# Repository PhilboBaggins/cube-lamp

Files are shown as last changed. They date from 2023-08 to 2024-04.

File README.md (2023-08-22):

# Cube lamp stand

A lamp that shines light through a cube of resin. Various junk could be embedded in the resin to make it look interesting.

TODO: Add photo of completed lamp

## Licence

Copyright © 2023 Phil Baldwin

This work is licensed under a Creative Commons Attribution-ShareAlike 4.0 International License.

You should have received a copy of the license along with this work. If not, see <http://creativecommons.org/licenses/by-sa/4.0/>.

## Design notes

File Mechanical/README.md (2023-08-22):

# Cube lamp stand

A stand designed to hold the [PCB](../PCB/) and resin cube. The stand is intended to be 3D printed.

TODO: Add photo

## Design notes

There are several models of the stand. All were designed in [Blender](https://www.blender.org/) and saved as `Cube lamp stand.blend`. Each model was exported from Blender as an `.stl` file:

| Model | Description |
| --- | --- |
| `Cube lamp stand-Stand_1.stl` | Largest model. Based on a half sphere when the hole for the resin  cube cut into it |
| `Cube lamp stand-Stand_2.stl` | Shorter, flatter model. Basically a disk with the resin cube sitting mostly on top of it (not recessed in deeply) |
| `Cube lamp stand-Stand_2_001.stl` | A more rounded version of `Cube lamp stand-Stand_2.stl` |

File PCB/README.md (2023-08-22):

# Lamp board

A PCB that holds the electronics for the lamp. It is designed to fit inside the base of the lamp stand.

The board has 3 red, 3 green and 3 blue LEDs, each controlled by FET driven by a separate GPIO lines. The intention is to drive the LEDs with PWM to create a wide range of colours.

A Raspberry Pi Pico micro-controller board is mounted on the bottom of the PCB. The Pico is powered from USB. Firmware could be written to control the LEDs independantly or from commands send from a computer of USB. A Pico-W could be used instead of a Pico to allow the lamp to be controlled over WiFi or Bluetooth.




TODO: Add photo of completed board

## Licence

Copyright © 2023 Phil Baldwin

This work is licensed under a Creative Commons Attribution-ShareAlike 4.0 International License.

You should have received a copy of the license along with this work. If not, see <http://creativecommons.org/licenses/by-sa/4.0/>.

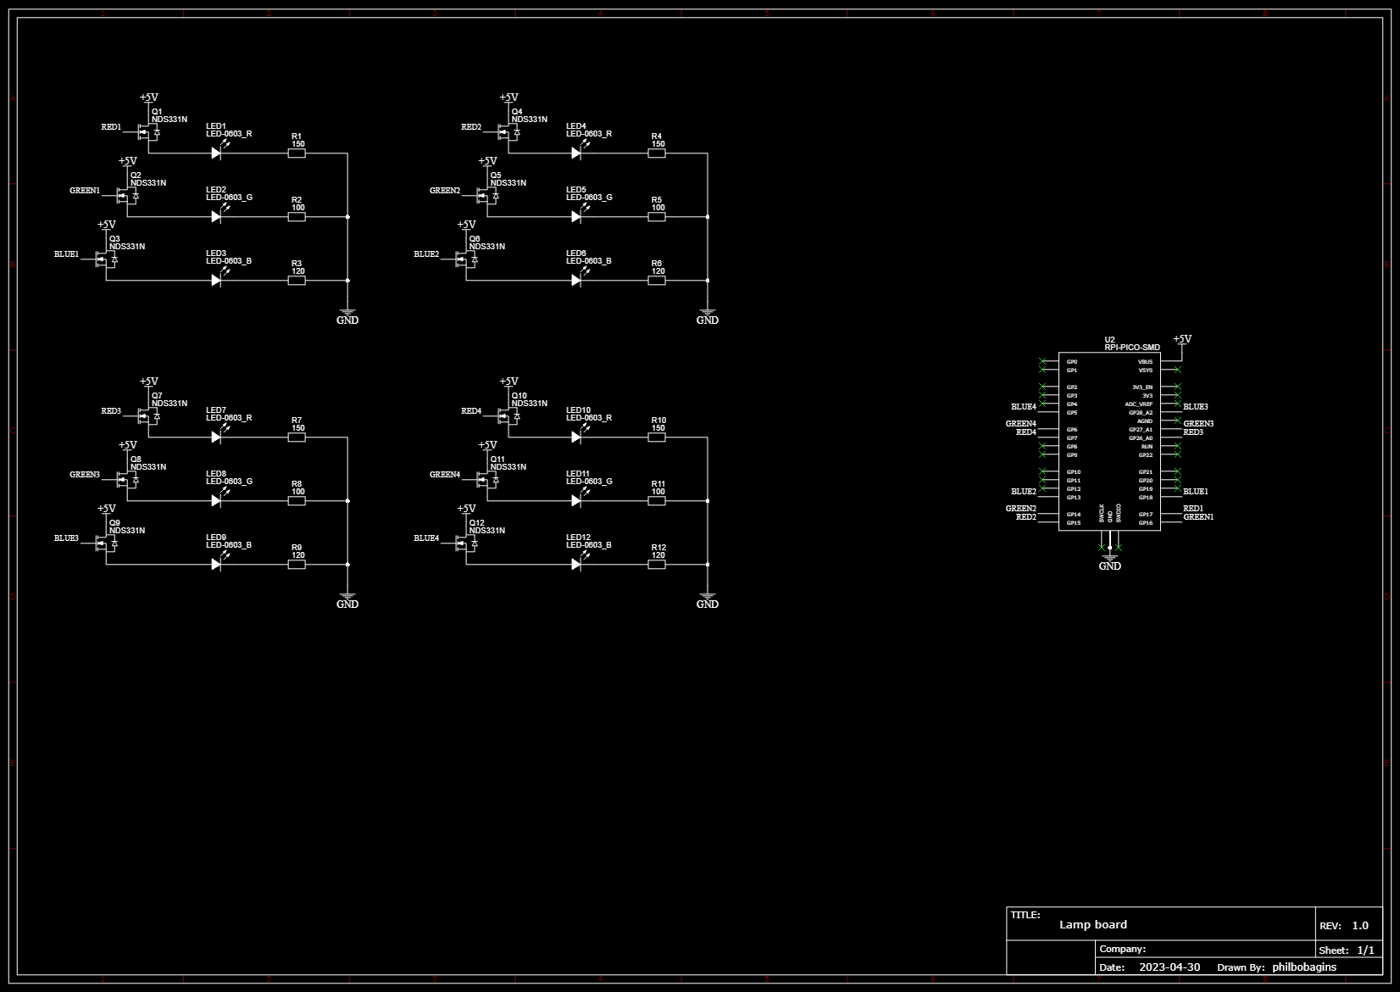
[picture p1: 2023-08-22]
PCB/Exports-v1.0/Schematic.png

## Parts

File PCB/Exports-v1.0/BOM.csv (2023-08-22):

ID | Name | Designator | Footprint | Quantity | Manufacturer Part | Manufacturer | Supplier | Supplier Part | Price
1 | LED-0603_R | LED1,LED4,LED7,LED10 | LED0603_RED | 4 | 19-217/R6C-AL1M2VY/3T | EVERLIGHT(台湾亿光) | LCSC | C72044 | 0.016
2 | LED-0603_G | LED2,LED5,LED8,LED11 | LED0603_GREEN | 4 | 19-217/GHC-YR1S2/3T | EVERLIGHT(台湾亿光) | LCSC | C72043 | 0.027
3 | LED-0603_B | LED3,LED6,LED9,LED12 | LED0603_BLUE | 4 | 19-217/BHC-ZL1M2RY/3T | EVERLIGHT(台湾亿光) | LCSC | C72041 | 0.018
4 | NDS331N | Q1,Q2,Q3,Q4,Q5,Q6,Q7,Q8,Q9,Q10,Q11,Q12 | SOT-23-3_L2.9-W1.3-P1.90-LS2.4-BR | 12 | NDS331N | onsemi(安森美) | LCSC | C192741
5 | 150 | R1,R4,R7,R10 | R0603 | 4
6 | 100 | R2,R5,R8,R11 | R0603 | 4
7 | 120 | R3,R6,R9,R12 | R0603 | 4
8 | RPI-PICO-SMD | U2 | RPI_PICO | 1 | SC0915 | Raspberry Pi | Digi-Key | 2648-SC0915CT-ND

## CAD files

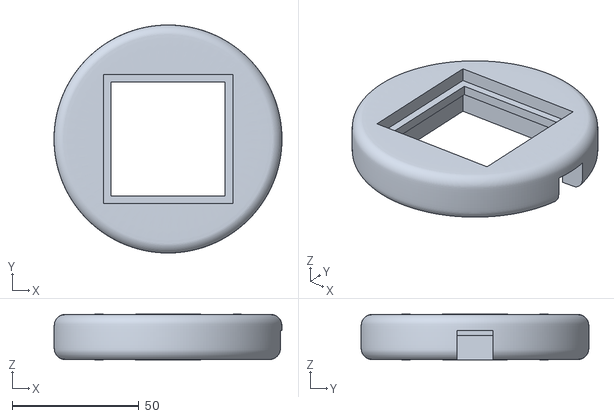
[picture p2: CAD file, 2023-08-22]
Mechanical/Cube lamp stand-Stand_2.stl
89.8 x 89.8 x 17.9

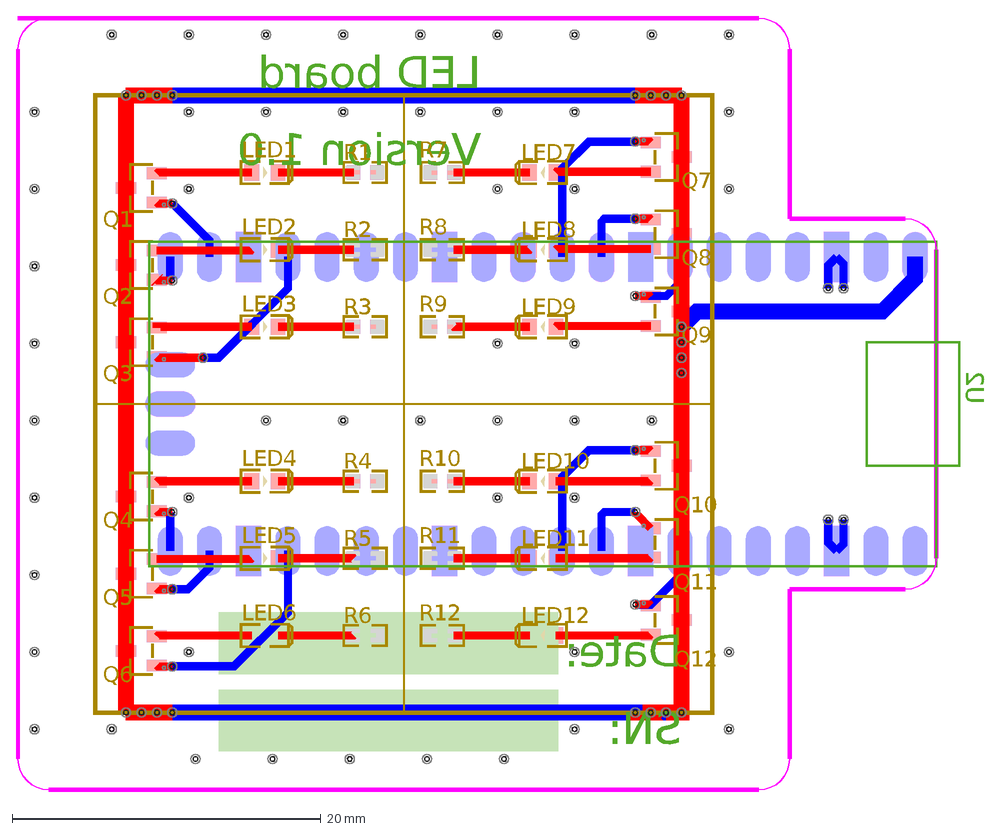
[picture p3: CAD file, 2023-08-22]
PCB/Exports-v1.0/PCB.dxf
LED board
Version 1.0
Date:
SN:
R1
R2
R3
R4
R5
R6
R7
R8
R9
R10
R11
R12
LED4
LED5
LED6
LED7
LED8
LED9
LED10
LED11
LED12
Q4
Q6
LED1
LED2
LED3
Q1
Q2
Q3
Q7
Q8
Q9
Q10
Q11
Q12
Q5
U2

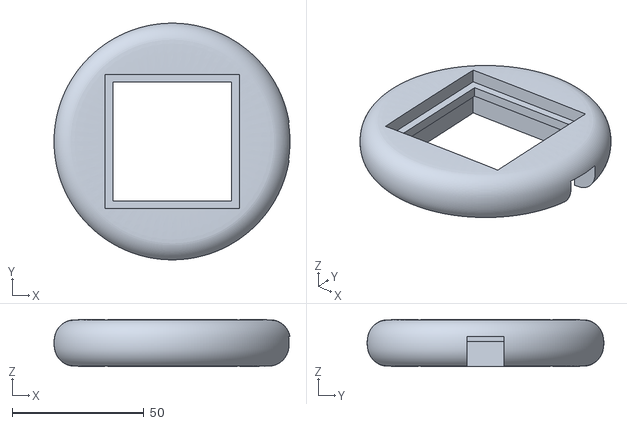
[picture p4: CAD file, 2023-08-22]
Mechanical/Cube lamp stand-Stand_2_001.stl
89.5 x 89.8 x 17.9

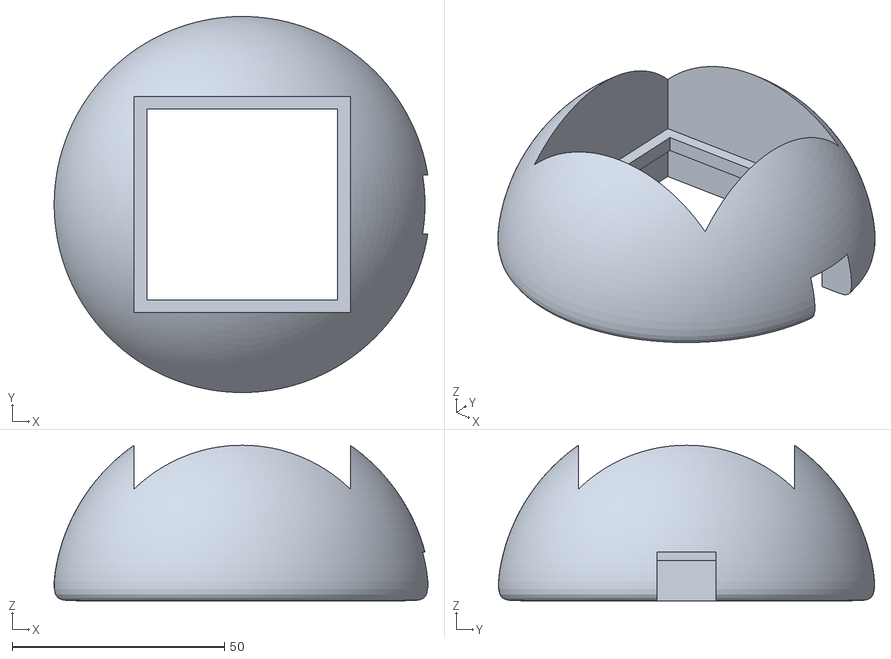
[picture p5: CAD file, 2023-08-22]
Mechanical/Cube lamp stand-Stand_1.stl
88.1 x 88.7 x 36.7

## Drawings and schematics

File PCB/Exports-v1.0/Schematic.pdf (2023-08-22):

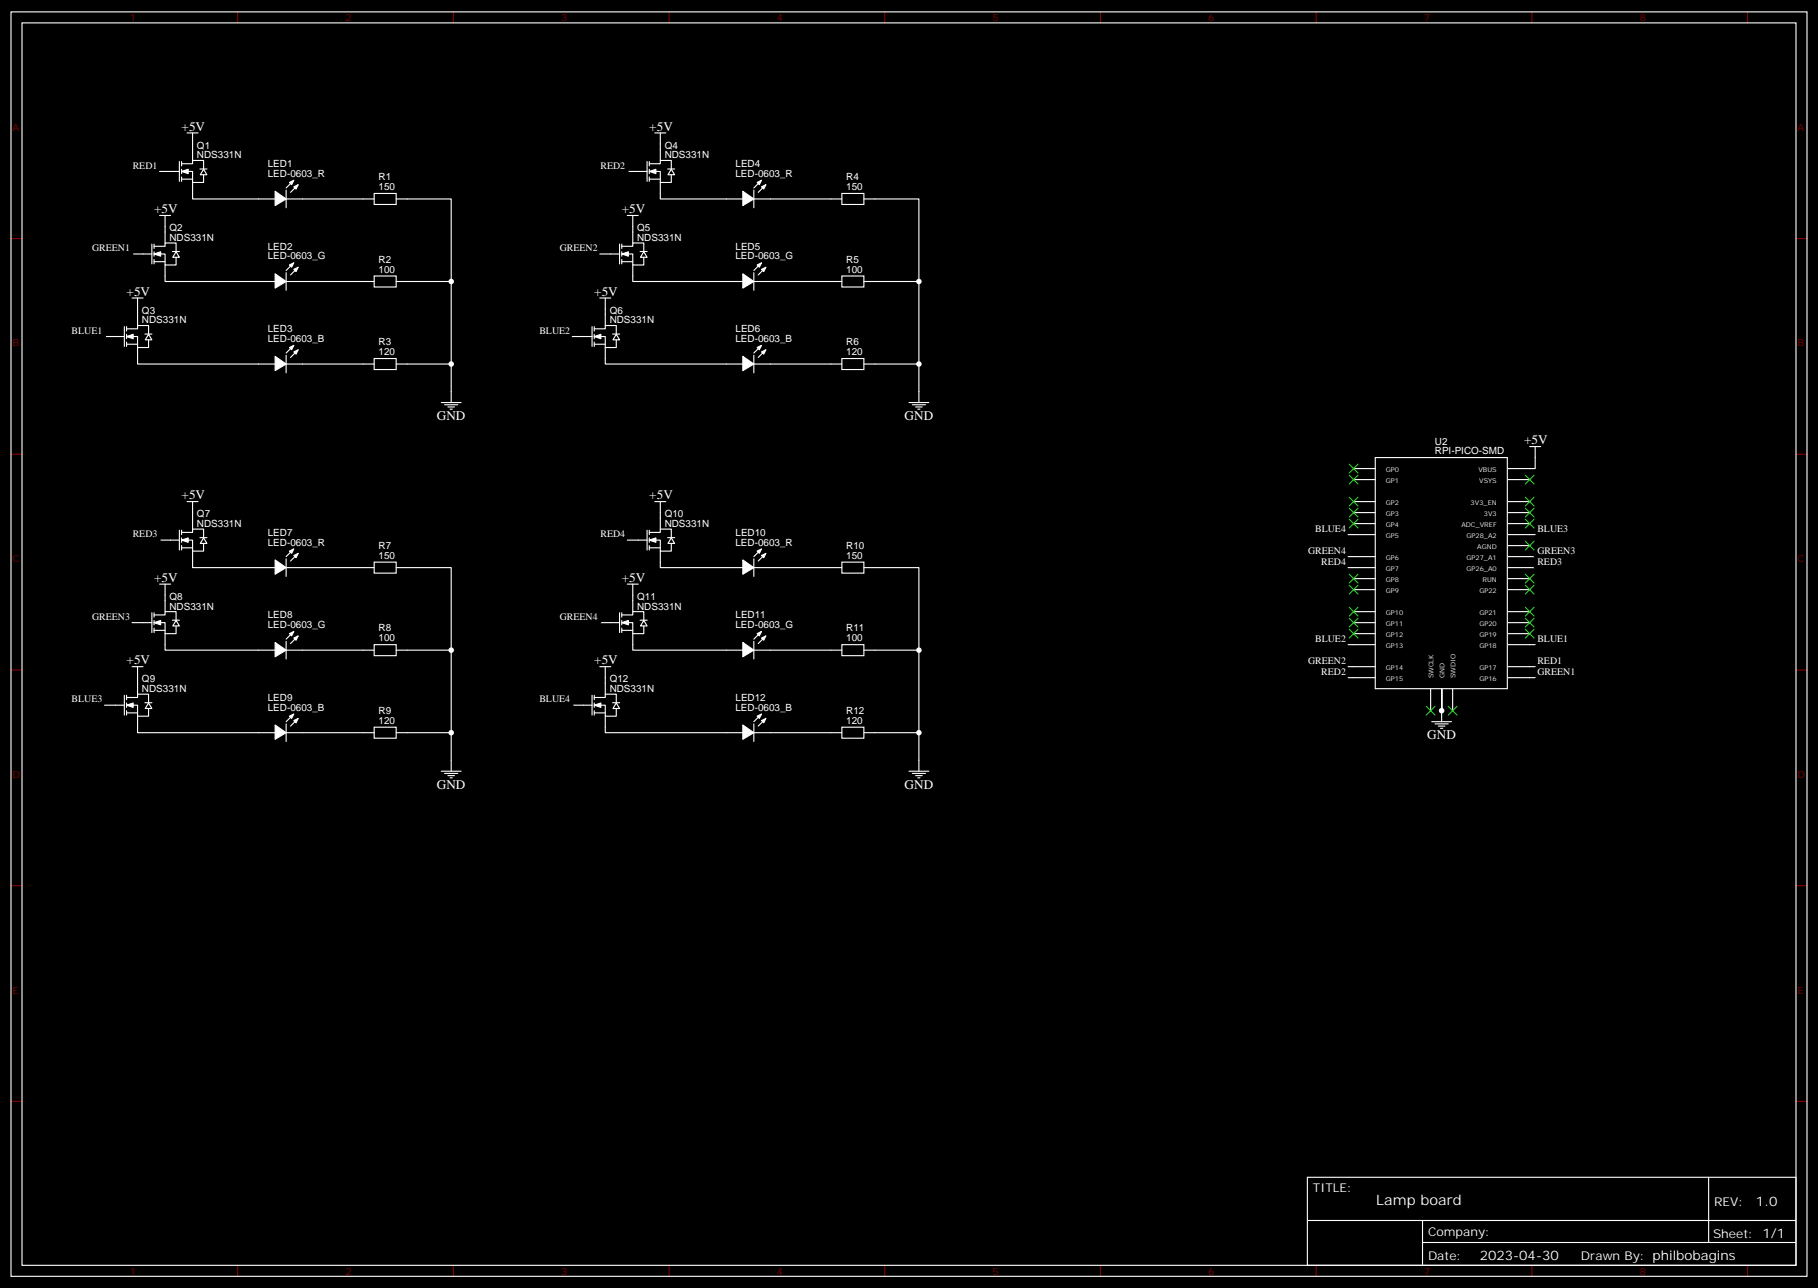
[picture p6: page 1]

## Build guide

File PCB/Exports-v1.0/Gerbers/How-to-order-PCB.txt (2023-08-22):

How to Order PCB

Please refer to:
https://docs.easyeda.com/en/PCB/Order-PCB

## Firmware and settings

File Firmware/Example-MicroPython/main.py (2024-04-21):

from machine import Pin, PWM
import time
import math

PIN_NUM_RED_1 = 17
PIN_NUM_RED_2 = 15
PIN_NUM_RED_3 = 26
PIN_NUM_RED_4 = 7

PIN_NUM_GRN_1 = 16
PIN_NUM_GRN_2 = 14
PIN_NUM_GRN_3 = 27
PIN_NUM_GRN_4 = 6

PIN_NUM_BLU_1 = 18
PIN_NUM_BLU_2 = 13
PIN_NUM_BLU_3 = 28
PIN_NUM_BLU_4 = 5

PIN_NUM_ALL_RED = [PIN_NUM_RED_1, PIN_NUM_RED_2, PIN_NUM_RED_3, PIN_NUM_RED_4]
PIN_NUM_ALL_GRN = [PIN_NUM_GRN_1, PIN_NUM_GRN_2, PIN_NUM_GRN_3, PIN_NUM_GRN_4]
PIN_NUM_ALL_BLU = [PIN_NUM_BLU_1, PIN_NUM_BLU_2, PIN_NUM_BLU_3, PIN_NUM_BLU_4]

DEFAULT_FREQ = 1000
DEFAULT_ITERATE_COLOUR_DELAY_MS = 5

def iterateColour(start, stop, step, delay):
    for i in range(int(start), int(stop), int(step)):
        #print(hex(i))
        yield i * i
        time.sleep_ms(delay)

def iterateColourUp(delay=DEFAULT_ITERATE_COLOUR_DELAY_MS):
        yield from iterateColour(0x0000, math.sqrt(0xFFFF), 1, delay)

def iterateColourDown(delay=DEFAULT_ITERATE_COLOUR_DELAY_MS):
        yield from iterateColour(math.sqrt(0xFFFF), 0x0000, -1, delay)

class CubeBoard:
    def __init__(self):
        self.ledRed = list(map(lambda p: PWM(Pin(p)), PIN_NUM_ALL_RED))
        self.ledGrn = list(map(lambda p: PWM(Pin(p)), PIN_NUM_ALL_GRN))
        self.ledBlu = list(map(lambda p: PWM(Pin(p)), PIN_NUM_ALL_BLU))

        for led in self.ledRed:
            led.freq(DEFAULT_FREQ)
        for led in self.ledGrn:
            led.freq(DEFAULT_FREQ)
        for led in self.ledBlu:
            led.freq(DEFAULT_FREQ)

    def setRed(self, duty):
        duty = int(duty)
        for led in self.ledRed:
            led.duty_u16(duty)

    def setGrn(self, duty):
        duty = int(duty)
        for led in self.ledGrn:
            led.duty_u16(duty)

    def setBlu(self, duty):
        duty = int(duty)
        for led in self.ledBlu:
            led.duty_u16(duty)

    def set(self, r, g, b):
        self.setRed(r)
        self.setGrn(g)
        self.setBlu(b)

    def off(self):
        self.set(0, 0, 0)

    def onFull(self):
        self.set(0xFFFF, 0xFFFF, 0xFFFF)

    def iterateColour(self, rangeGenerator, r, g, b, delay):
        for i in rangeGenerator(delay):
            rr = i if r else 0
            gg = i if g else 0
            bb = i if b else 0
            cubeBoard.set(rr, gg, bb)

    def iterateColourUp(self, r=False, g=False, b=False, delay=DEFAULT_ITERATE_COLOUR_DELAY_MS):
        self.iterateColour(iterateColourUp, r, g, b, delay)

    def iterateColourDown(self, r=False, g=False, b=False, delay=DEFAULT_ITERATE_COLOUR_DELAY_MS):
        self.iterateColour(iterateColourDown, r, g, b, delay)

cubeBoard = CubeBoard()
cubeBoard.off()

# # Cycle through colours
# cubeBoard.set(0xFFFF, 0x0000, 0x0000)  # Just red
# time.sleep(1.0)
# cubeBoard.set(0x0000, 0xFFFF, 0x0000)  # Just green
# time.sleep(1.0)
# cubeBoard.set(0x0000, 0x0000, 0xFFFF)  # Just blue
# time.sleep(1.0)

while True:
    # Red
    cubeBoard.iterateColourUp(True, False, False, 1)
    cubeBoard.iterateColourDown(True, False, False, 5)

    # Green
    cubeBoard.iterateColourUp(False, True, False, 1)
    cubeBoard.iterateColourDown(False, True, False, 5)

    # Blue
    cubeBoard.iterateColourUp(False, False, True, 1)
    cubeBoard.iterateColourDown(False, False, True, 5)

#cubeBoard.off()

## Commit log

2023-08-22 Add exports for v1.0 PCB
    [BOM.csv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]
2023-08-22 Add mechanical files
    [Cube lamp stand-Stand_1.stl, Cube lamp stand-Stand_2.stl, Cube lamp stand-Stand_2_001.stl]
2024-04-16 Add PCB/Calculations.ipynb
